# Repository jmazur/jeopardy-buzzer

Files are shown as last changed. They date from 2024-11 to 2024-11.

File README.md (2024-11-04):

# Jeopardy Buzzer
This project is a Jeopardy! inspired buzzer for home use. You can connect up to
10 contestants and 1 host to play trivia game. The first contestant to buzz in
locks all the other contestants out. 

The buzzers communicate over a local WIFI which can be configured in the
firmware.

## Hardware
This project uses an ESP 32 S2 SOLO. All schematics and PCB design was completed
using KiCAD. The full project can be found in the `pcb` folder.

There is a known issue with the spacing of the button contacts at the bottom of
the pcb, they need a little more space between them. They can still be used
as-is (which is why it didn't fixed earlier) but any new boards can use this
design change.

This project also uses a non-standard battery. I ran out of time to work on a
battery circuit to use a standard AA battery so I opted for a 
`3.2 Volt 600 mAh LiFePO4 14500 Battery` instead. It would be really nice to
change this to a single or a pair of AA or AAA batteries in a future version.

## Software
All firmware is compiled and sent to the ESP using the Arduino IDE. All files
are located in the `firmware` folder.

There is a flag called `IS_HOST` which differentiates buzzers between hosts and
contestants. There can only ever be 1 host per WIFI network. There can be up to
10 contestants before the network stops allowing new connections.

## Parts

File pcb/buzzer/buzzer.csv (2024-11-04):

Source: | /Users/justinmazur/Documents/buzzer/buzzer.kicad_sch
Date: | 2023 August 20, Sunday 00:07:58
Tool: | Eeschema 7.0.6-0
Generator: | /Applications/KiCad/KiCad.app/Contents/SharedSupport/plugins/bom_csv_grouped_by_value.py
Component Count: | 29
Collated Components:
Item | Qty | Reference(s) | Value | LibPart | Footprint | Datasheet | DNP | MANUFACTURER | PARTREV | STANDARD | Sim.Device | Sim.Pins
1 | 5 | C1, C2, C3, C5, C6 | 22UF | Device:C | Capacitor_SMD:C_1206_3216Metric_Pad1.33x1.80mm_HandSolder | ~
2 | 1 | C4 | 150UF | Device:C | Capacitor_Tantalum_SMD:CP_EIA-3528-12_Kemet-T_Pad1.50x2.35mm_HandSolder | ~
3 | 2 | Conn_Button_1, Conn_Button_2 | ~ | Z00C-4G7L1-1100:Spring_Contact | Library:Z00C-4G7L1-11000
4 | 2 | D1, D2 | LED | Device:LED | LED_THT:LED_D5.0mm_Clear | ~
5 | 1 | D3 | D | Device:D | Diode_THT:D_DO-35_SOD27_P7.62mm_Horizontal | ~ |  |  |  |  | D | 1=K 2=A
6 | 1 | D4 | BAT60A | Diode:BAT60A | Diode_SMD:D_SOD-323 | https://www.infineon.com/dgdl/Infineon-BAT60ASERIES-DS-v01_01-en.pdf?fileId=db3a304313d846880113def70c9304a9
7 | 1 | J1 | Conn_02x01 | Connector_Generic:Conn_02x01 | Jmazur:Jm 1x AAA Battery Holder | ~
8 | 1 | JP1 | HOST | Jumper:SolderJumper_2_Bridged | Jumper:SolderJumper-2_P1.3mm_Open_TrianglePad1.0x1.5mm | ~
9 | 1 | JP2 | CONTESTANT | Jumper:SolderJumper_2_Bridged | Jumper:SolderJumper-2_P1.3mm_Open_TrianglePad1.0x1.5mm | ~
10 | 1 | L1 | L | Device:L | Inductor_SMD:L_1008_2520Metric_Pad1.43x2.20mm_HandSolder | ~
11 | 1 | LS1 | Speaker | Device:Speaker | Connector_Wire:SolderWire-1sqmm_1x02_P7.8mm_D1.4mm_OD3.9mm | ~
12 | 1 | R1 | 10k | Device:R | Resistor_SMD:R_0402_1005Metric_Pad0.72x0.64mm_HandSolder | ~
13 | 1 | R2 | 10K | Device:R | Resistor_SMD:R_0402_1005Metric_Pad0.72x0.64mm_HandSolder | ~
14 | 1 | TP1 | GND | Connector:TestPoint | TestPoint:TestPoint_Pad_D3.0mm | ~
15 | 1 | TP2 | USB_D + | Connector:TestPoint | TestPoint:TestPoint_Pad_D3.0mm | ~
16 | 1 | TP3 | USB_D - | Connector:TestPoint | TestPoint:TestPoint_Pad_D3.0mm | ~
17 | 1 | TP4 | 3V3 | Connector:TestPoint | TestPoint:TestPoint_Pad_D3.0mm | ~
18 | 1 | TP5 | BOOT | Connector:TestPoint | TestPoint:TestPoint_Pad_D3.0mm | ~
19 | 1 | TP6 | EN | Connector:TestPoint | TestPoint:TestPoint_Pad_D3.0mm | ~
20 | 1 | TP7 | BATT | Connector:TestPoint | TestPoint:TestPoint_Pad_D3.0mm | ~
21 | 1 | U1 | ESP32-S2-SOLO | PCM_Espressif:ESP32-S2-SOLO | PCM_Espressif:ESP32-S2-SOLO | https://www.espressif.com/sites/default/files/documentation/esp32-s2-solo_esp32-s2-solo-u_datasheet_en.pdf
22 | 1 | U2 | PAM8301AAF | PAM8301AAF:PAM8301AAF | resources:SOT95P280X145-6N |  |  | Diodes Inc. | 1-3 | IPC-7351B
23 | 1 | U3 | TPS613221ADBVR | TPS613221ADBVR:TPS613221ADBVR | resources:SOT95P280X145-5N

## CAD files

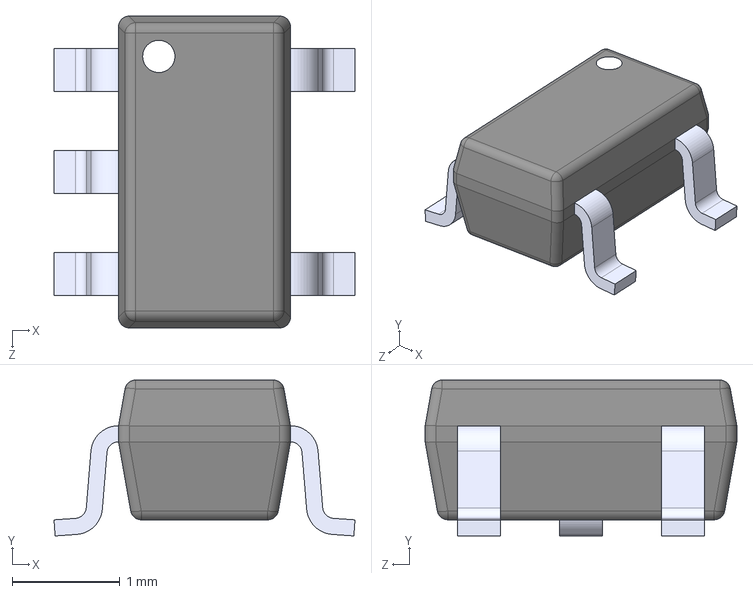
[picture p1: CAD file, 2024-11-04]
pcb/buzzer/resources/TPS613221ADBVR.step
2.80 x 1.45 x 2.90 mm

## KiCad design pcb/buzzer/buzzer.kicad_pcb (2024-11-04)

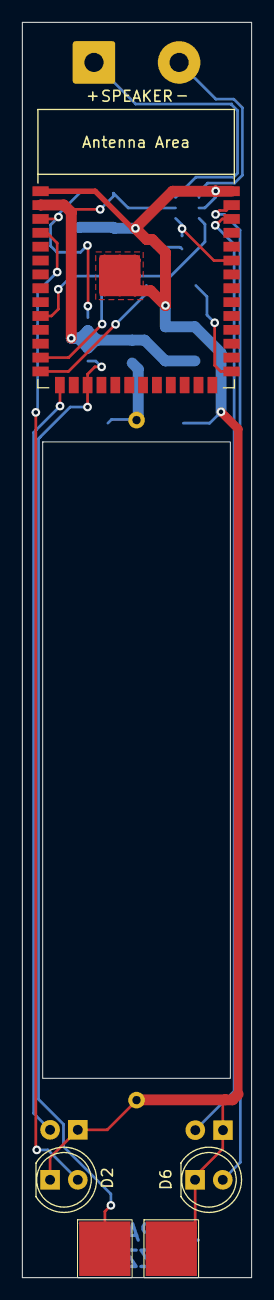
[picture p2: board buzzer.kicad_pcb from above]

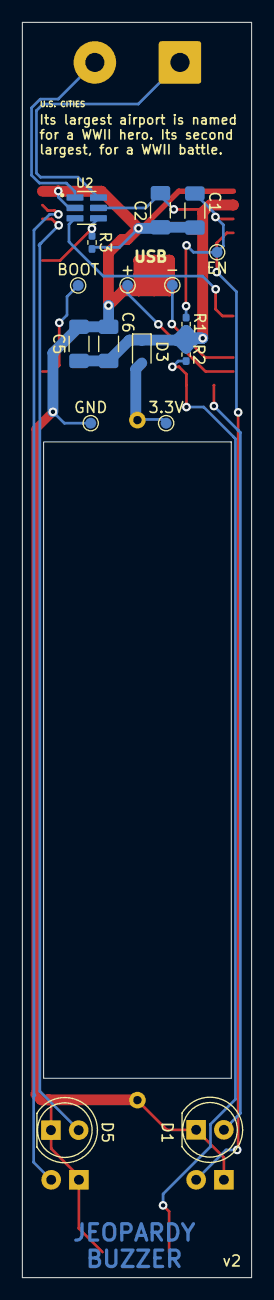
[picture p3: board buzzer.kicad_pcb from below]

Board: 2 copper layers, 21.0 x 115.0 mm, 24 parts (17 on the bottom side), 16 nets.

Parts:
3.3V: BATT; TestPoint_Pad_D1.0mm
+: USB_D +; TestPoint_Pad_D1.0mm
-: USB_D -; TestPoint_Pad_D1.0mm
BOOT: BOOT; TestPoint_Pad_D1.0mm
C1, C2, C5, C6: 22UF; C_1206_3216Metric_Pad1.33x1.80mm_HandSolder
Conn_Button_1, Conn_Button_2: Z00C-4G7L1-11000
D1, D2, D5, D6: LED; LED_D5.0mm_Clear
D3: BAT60A; D_SOD-323
EN: EN; TestPoint_Pad_D1.0mm
GND: GND; TestPoint_Pad_D1.0mm
J1: Conn_02x01; JM BATT 14500
R1: 10k; R_0402_1005Metric_Pad0.72x0.64mm_HandSolder
R2, R3: 10K; R_0402_1005Metric_Pad0.72x0.64mm_HandSolder
SPEAKER: Speaker; SolderWire-1sqmm_1x02_P7.8mm_D1.4mm_OD3.9mm
U1: ESP32-S2-SOLO
U2: PAM8301AAF; SOT95P280X145-6N

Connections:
3V3: C2.1, C5.1, C6.2, D3.1 (K), R1.1, R2.1, U1.2 (3V3), U2.5 (VDD)
AUDIO_SD: R3.1, U1.35 (MTMS/GPIO42), U2.4 (~SD)
BUTTON: Conn_Button_1.1, R2.2, U1.17 (GPIO9/TOUCH9/ADC1_CH8/FSPIHD)
GND: C1.2, C2.2, C5.2, C6.1, Conn_Button_2.1, D1.1 (K), D2.1 (K), D5.1 (K), D6.1 (K), GND.1, J1.2, R3.2, U1.1 (GND), U1.40 (GND), U1.41 (GND), U2.2 (GND)
LED1: D6.2 (A), U1.39 (GPIO1/TOUCH1/ADC1_CH0)
LED2: D5.2 (A), U1.38 (GPIO2/TOUCH2/ADC1_CH1)
LED3: D1.2 (A), U1.15 (GPIO3/TOUCH3/ADC1_CH2)
LED4: D2.2 (A), U1.4 (GPIO4/TOUCH4/ADC1_CH3)
unnamed: 3.3V.1, D3.2 (A), J1.1
unnamed: C1.1, EN.1, R1.2, U1.3 (EN)
unnamed: BOOT.1, U1.27 (GPIO0)
unnamed: U1.10 (GPIO17/U1TXD/ADC2_CH6/DAC_1), U2.3 (IN)
unnamed: -.1, U1.13 (GPIO19/U1RTS/ADC2_CH8/CLK_OUT2/USB_D-)
unnamed: +.1, U1.14 (GPIO20/U1CTS/ADC2_CH9/CLK_OUT1/USB_D+)
unnamed: SPEAKER.1, U2.6 (OUT+)
unnamed: SPEAKER.2, U2.1 (OUT-)

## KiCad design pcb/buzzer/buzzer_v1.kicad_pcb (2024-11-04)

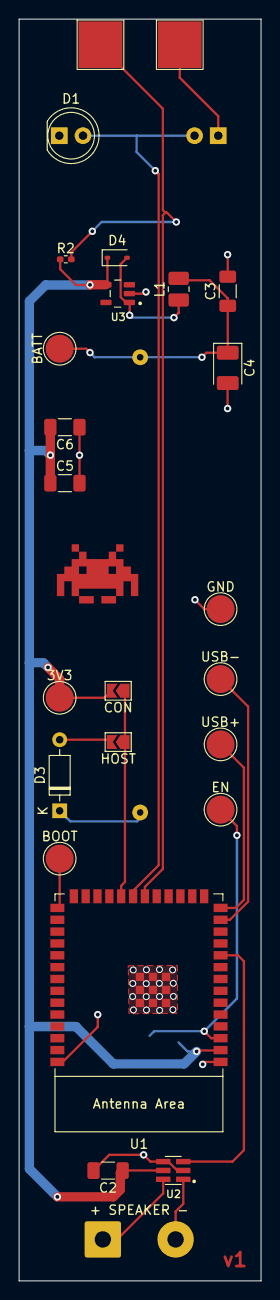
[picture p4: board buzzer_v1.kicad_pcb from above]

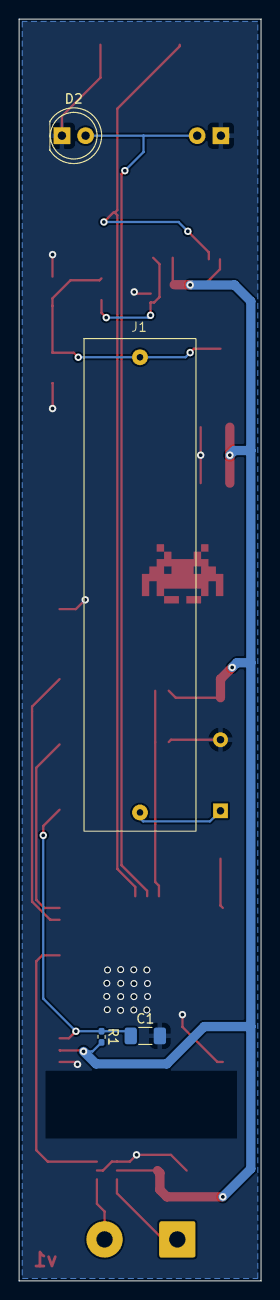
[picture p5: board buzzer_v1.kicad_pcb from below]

Board: 2 copper layers, 25.9 x 135.3 mm, 29 parts (4 on the bottom side), 15 nets.

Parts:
3V3: 3V3; TestPoint_Pad_D3.0mm
+ SPEAKER -: Speaker; SolderWire-1sqmm_1x02_P7.8mm_D1.4mm_OD3.9mm
BATT: BATT; TestPoint_Pad_D3.0mm
BOOT: BOOT; TestPoint_Pad_D3.0mm
C1, C2, C3, C5, C6: 22UF; C_1206_3216Metric_Pad1.33x1.80mm_HandSolder
C4: 150UF; CP_EIA-3528-12_Kemet-T_Pad1.50x2.35mm_HandSolder
CON: CONTESTANT; SolderJumper-2_P1.3mm_Open_TrianglePad1.0x1.5mm
Conn_Button_1, Conn_Button_2: Z00C-4G7L1-11000
D1, D2: LED; LED_D5.0mm_Clear
D3: D; D_DO-35_SOD27_P7.62mm_Horizontal
D4: BAT60A; D_SOD-323
EN: EN; TestPoint_Pad_D3.0mm
GND: GND; TestPoint_Pad_D3.0mm
HOST: HOST; SolderJumper-2_P1.3mm_Open_TrianglePad1.0x1.5mm
J1: Conn_02x01; Jm 1x AAA Battery Holder
L1: L; L_1008_2520Metric_Pad1.43x2.20mm_HandSolder
R1: 10k; R_0402_1005Metric_Pad0.72x0.64mm_HandSolder
R2: 10K; R_0402_1005Metric_Pad0.72x0.64mm_HandSolder
U1: ESP32-S2-SOLO
U2: PAM8301AAF; SOT95P280X145-6N
U3: TPS613221ADBVR; SOT95P280X145-5N
USB+: USB_D +; TestPoint_Pad_D3.0mm
USB-: USB_D -; TestPoint_Pad_D3.0mm

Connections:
3V3: 3V3.1, C2.1, C5.1, C6.2, CON.2 (B), D4.1 (K), R1.1, R2.1, U1.2 (3V3), U2.5 (VDD), U3.4 (VOUT)
GND: C1.2, C2.2, C3.2, C4.2, C5.2, C6.1, Conn_Button_2.1, D1.1 (K), D2.1 (K), D3.2 (A), GND.1, HOST.2 (B), U1.1 (GND), U1.40 (GND), U1.41 (GND), U2.2 (GND), U2.4 (~SD), U3.2 (GND)
unnamed: CON.1 (A), HOST.1 (A), U1.22 (GPIO14/TOUCH14/ADC2_CH3/FSPIWP/FSPIDQS)
unnamed: D1.2 (A), D2.2 (A), U1.21 (GPIO13/TOUCH13/ADC2_CH2/FSPIQ/FSPIIO7)
unnamed: D3.1 (K), J1.2
unnamed: D4.2 (A), L1.1, U3.1 (SW)
unnamed: BATT.1, C3.1, C4.1, J1.1, L1.2
unnamed: C1.1, EN.1, R1.2, U1.3 (EN)
unnamed: BOOT.1, U1.27 (GPIO0)
unnamed: Conn_Button_1.1, R2.2, U1.20 (GPIO12/TOUCH12/ADC2_CH1/FSPICLK/FSPIIO6)
unnamed: U1.10 (GPIO17/U1TXD/ADC2_CH6/DAC_1), U2.3 (IN)
unnamed: U1.13 (GPIO19/U1RTS/ADC2_CH8/CLK_OUT2/USB_D-), USB-.1
unnamed: U1.14 (GPIO20/U1CTS/ADC2_CH9/CLK_OUT1/USB_D+), USB+.1
unnamed: + SPEAKER -.1, U2.6 (OUT+)
unnamed: + SPEAKER -.2, U2.1 (OUT-)

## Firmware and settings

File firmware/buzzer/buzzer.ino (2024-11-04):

// Host or client build
#define IS_HOST           false
#define BOARD_VERSION     2

// Hardware Pinout
#if BOARD_VERSION == 1
  #define LED_PIN_1         1
  #define LED_PIN_2         -1
  #define LED_PIN_3         -1
  #define LED_PIN_4         -1
  #define BUTTON_PIN        9
  #define SPEAKER_PIN       17
  #define SPEAKER_CHANNEL   0
  #define AMP_PIN           -1
#endif

#if BOARD_VERSION == 2
  #define LED_PIN_1         1
  #define LED_PIN_2         2
  #define LED_PIN_3         3
  #define LED_PIN_4         4
  #define BUTTON_PIN        9
  #define SPEAKER_PIN       17
  #define SPEAKER_CHANNEL   0
  #define AMP_PIN           42
#endif

// possible LED states
#define LED_OFF     0
#define LED_ON      1
#define LED_SPIN    2
#define LED_PULSE   3
#define LED_HALF    4

#define BUZZ_DURATION  3000

#include <WiFi.h>

#if !IS_HOST
  #include <HTTPClient.h>
#endif

#if IS_HOST
  #include <WebServer.h>
  WebServer server(80);
#endif

const char* ssid = "jeopardy";
const char* password = "idontknow";

bool buzzed = false;
bool buttonPressed = false;
bool muted = false;
bool setupComplete = false;

void setup() {
  // LED setup
  pinMode(LED_PIN_1, OUTPUT);
  pinMode(LED_PIN_2, OUTPUT);
  pinMode(LED_PIN_3, OUTPUT);
  pinMode(LED_PIN_4, OUTPUT);

  // Button setup
  pinMode(BUTTON_PIN, INPUT);
  
  // Audio setup
  pinMode(SPEAKER_PIN, OUTPUT);
  #if AMP_PIN >= 0
    pinMode(AMP_PIN, OUTPUT);
    digitalWrite(AMP_PIN, LOW);
  #endif

  setupSpeaker();
  setupBuzzer();
}

void loop() {
  loopBuzzer();
  powerOffWarning();
}

void IRAM_ATTR pressButton() {
  if (!setupComplete) {
    playDoubleBoop();
    muted = true;
  } else {
    buttonPressed = true;
  }
  detachInterrupt(BUTTON_PIN);
}

void buttonReady() {
  attachInterrupt(BUTTON_PIN, pressButton, FALLING);
}

// if the buzzer is powered for more than 2 hours, 
// we need to alert to remove the battery
void powerOffWarning() {
  if (millis() < 7200000) { // 2 hours
    return;
  }

  buttonReady();
  int counter = 0;

  while(counter < 50) {
    if (buttonPressed) {
      resetPowerOffWarning();
    }
    
    ledSet(LED_HALF);
    delay(500);
    ledSet(LED_OFF);
    delay(500);
  }

  playBoop();
}

void resetPowerOffWarning() {
  ESP.restart();
}

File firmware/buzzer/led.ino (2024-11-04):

// define the maximum allowed brightness
#define LED_MAX     124

int ledState = LED_OFF;
int led1brightness = 0;
int led2brightness = 0;
int led3brightness = 0;
int led4brightness = 0;
unsigned long nextLedUpdate = 0;
bool pulseDirection = true;

void ledSet(int state) {
  ledState = state;
  ledUpdate();
}

void ledUpdate() {
  switch (ledState) {
    case LED_OFF:
      ledOff();
      break;
    case LED_ON:
      ledOn();
      break;
    case LED_SPIN:
      ledSpin();
      break;
    case LED_PULSE:
      ledPulse();
      break;
    case LED_HALF:
      ledHalfOn();
      break;
  }

  analogWrite(LED_PIN_1, led1brightness);
  analogWrite(LED_PIN_2, led2brightness);
  analogWrite(LED_PIN_3, led3brightness);
  analogWrite(LED_PIN_4, led4brightness);
}

void ledOff() {
  led1brightness = 0;
  led2brightness = 0;
  led3brightness = 0;
  led4brightness = 0;
  nextLedUpdate = 0;
}

void ledOn() {
  led1brightness = LED_MAX;
  led2brightness = LED_MAX;
  led3brightness = LED_MAX;
  led4brightness = LED_MAX;
  nextLedUpdate = 0;
}

void ledHalfOn() {
  int newbrightness = round(LED_MAX / 2);
  led1brightness = newbrightness;
  led2brightness = newbrightness;
  led3brightness = newbrightness;
  led4brightness = newbrightness;
  nextLedUpdate = 0;
}

void ledSpin() {
  if (millis() < nextLedUpdate) {
    return;
  }
  
  if (nextLedUpdate == 0) {
    led1brightness = LED_MAX;
    led2brightness = 0;
    led3brightness = 0;
    led4brightness = 0;
  } else {
    led1brightness = (led4brightness == LED_MAX) ? LED_MAX : 0;
    led2brightness = (led1brightness == LED_MAX) ? LED_MAX : 0;
    led3brightness = (led2brightness == LED_MAX) ? LED_MAX : 0;
    led4brightness = (led3brightness == LED_MAX) ? LED_MAX : 0;
  }

  nextLedUpdate = millis() + 300;
}

void ledPulse() {
  if (millis() < nextLedUpdate) {
    return;
  }

  if (led1brightness == 0) {
    pulseDirection = true;
  }

  if (led1brightness == LED_MAX) {
    pulseDirection = false;
  }

  int nextBrightness = 0;
  
  if (pulseDirection) {
    nextBrightness = led1brightness + 1;
  } else {
    nextBrightness = led1brightness - 1;
  }

  if (nextBrightness > LED_MAX) {
    nextBrightness = LED_MAX;
  }

  if (nextBrightness < 0) {
    nextBrightness = 0;
  }

  led1brightness = nextBrightness;
  led2brightness = nextBrightness;
  led3brightness = nextBrightness;
  led4brightness = nextBrightness;

  nextLedUpdate = millis() + 75;
}
